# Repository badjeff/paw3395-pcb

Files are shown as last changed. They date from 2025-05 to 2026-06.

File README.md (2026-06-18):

# PAW3395 PCB

PixArt [**PAW3395DM-T6QU**](https://www.pixart.com/products-detail/129/PAW3395DM-T6QU) low power laser mouse sensor breakout board.

- Compatible to **PAW3950DM-T5QU**.
- Be operated with 3.3V voltage level ONLY.
- Outlined as narrow as possible for side mount horizontally and perpendicular on low profile keyboards.
- Developed for [zmk-paw3395-driver](https://github.com/badjeff/zmk-paw3395-driver) and [zmk-paw3950-driver](https://github.com/badjeff/zmk-paw3950-driver)

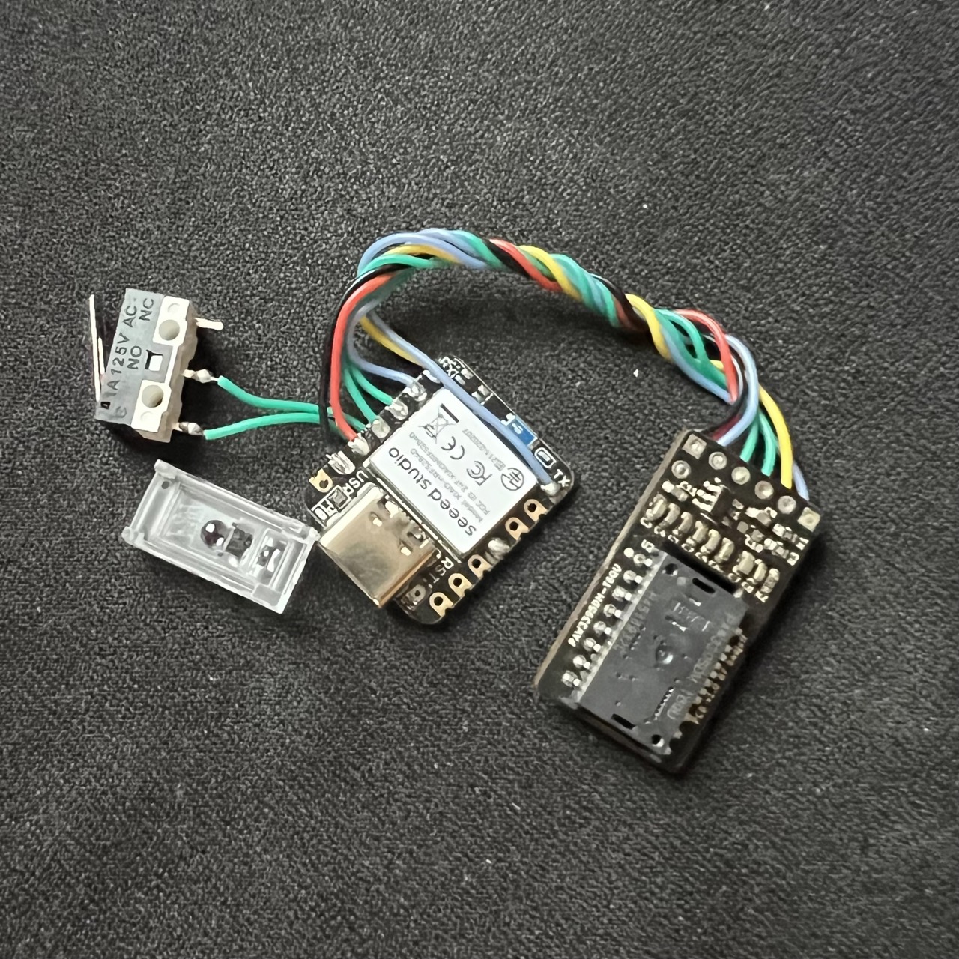
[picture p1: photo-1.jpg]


*Figure 1: Size comparing to Seeed XIAO BLE*

## PCB

Online preview avaliable [here](https://kicanvas.org/?github=https%3A%2F%2Fgithub.com%2Fbadjeff%2Fpaw3395-pcb), powered by [KiCanvas](https://github.com/theacodes/kicanvas).

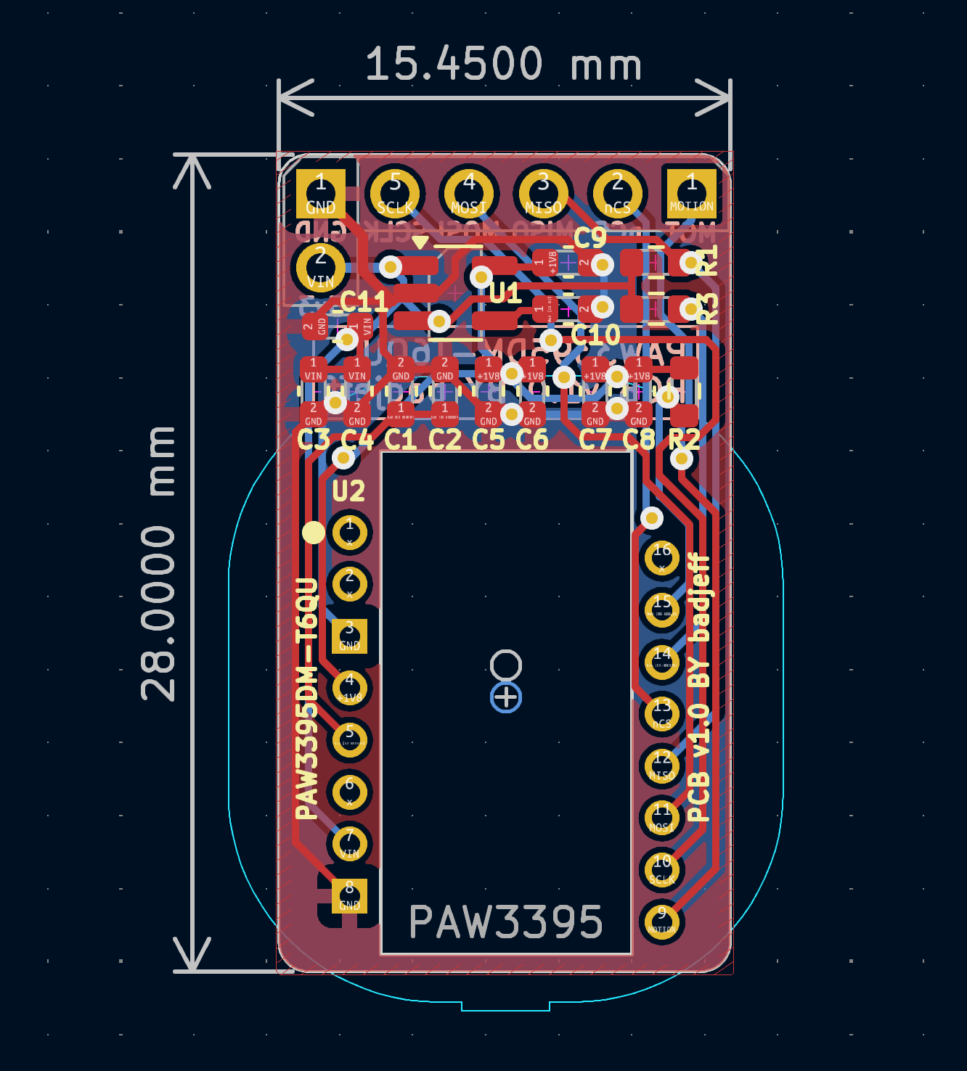
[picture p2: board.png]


*Figure 2: PCB edgecuts dimension*

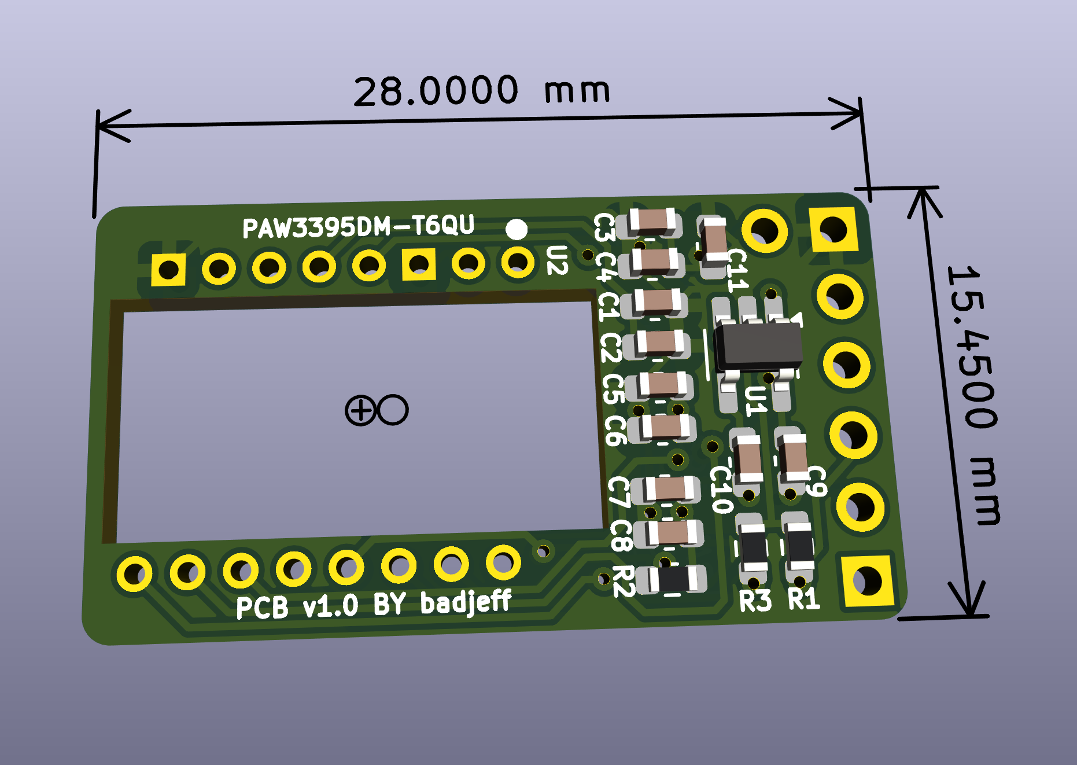
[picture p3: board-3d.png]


*Figure 3: PCB 3D View - 1.6mm FR4*

### BOM

|Designator|Footprint|Quantity|Value|LCSC Part #|
|-|-|-|-|-|
|C1|SMD 0603|1|4.7uF||
|C11, C9|SMD 0603|2|1uF||
|C2, C4, C5|SMD 0603|3|100nF||
|C3, C6, C8|SMD 0603|3|10uF||
|C7|SMD 0603|1|22uF||
|C10|SMD 0603|1|DNI||
|R1|SMD 0603|1|10K|C25804|
|R2|SMD 0603|1|4.7|C23164|
|R3|SMD 0603|1|2M|C22976|
|U1|SOT-23-5|1|TLV74318PDBVR||
|U2|PAW3395DM-T6QU|1|PAW3395||
|  |PAW3950DM-T5QU|1|PAW3950||

- DNI: don't install.
- SMD 0603 (Imperial) aka 1608 Metric.
- ~~`U1` LDO can be replace by RT9193-18GB, change `C10` to 22nF.~~
- `U1` LDO can be replace by XC6219B182MR or TLV75519PDBVR
- `C1` can be replace by 3.3uF.
- For **PAW3395** Option
  * PAW3395DM-T6QU needs to be used with *compact* LOAE-LSI1 lens, or *chonky* LM19-LSI lens.
- For **PAW3950** Option
  * PAW3950DM-T5QU needs to be used with *compact* LOAE-LSI1 lens, or *chonky* LM19-LSI lens.
  * `R1` should be DNI
  * `R2` should be closed (with zero ohm resistor)
  * Pin 2 & 3 should be connecting with a 2.2uf capicator

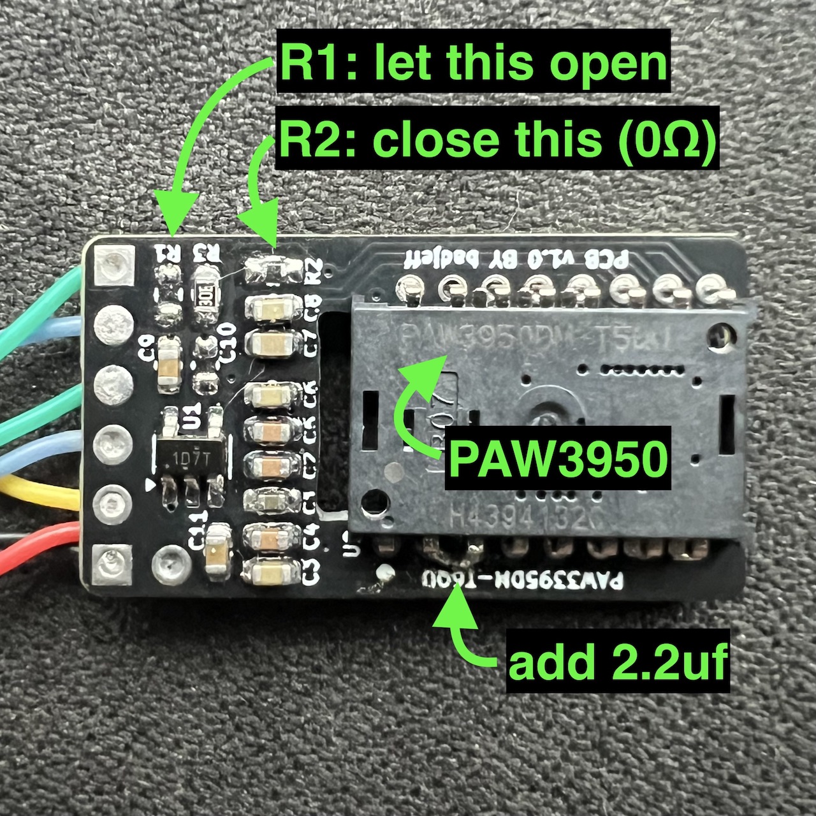
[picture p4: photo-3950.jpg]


*Figure 4: PAW3950 option

### Board Characteristics

- Copper layer count: 2
- Board thickness: 1.6 mm
- Board overall dimensions: 15.5 x 28 mm

### Voltage level config

- 3.3V logic
- VIN: 3.3V

## License

Available under the [CERN-OHL-P v2](/LICENSE) permissive license.

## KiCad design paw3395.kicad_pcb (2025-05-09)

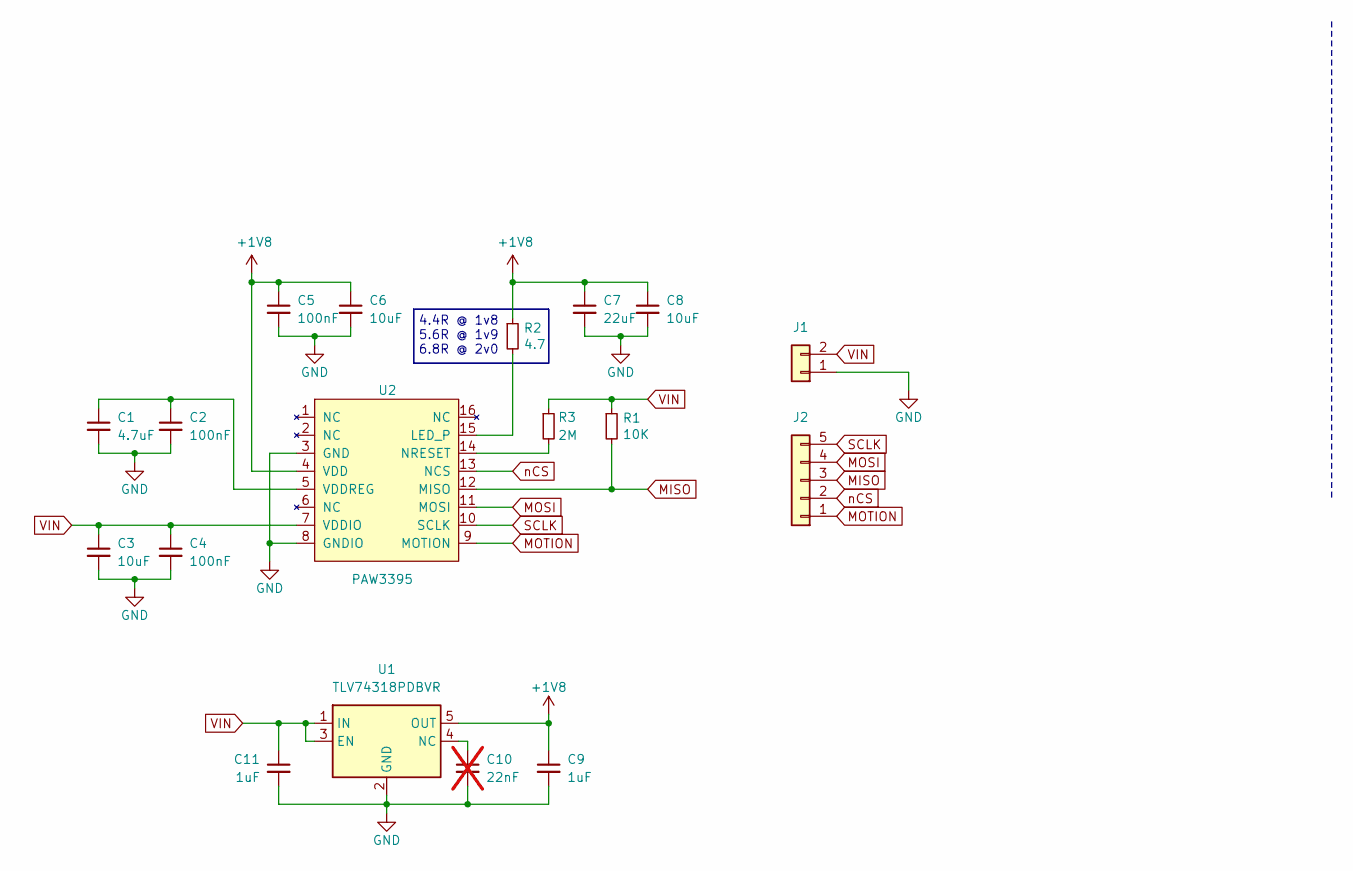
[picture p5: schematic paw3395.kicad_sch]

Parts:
C1: 4.7uF; C_0603_1608Metric
C2, C4, C5: 100nF; C_0603_1608Metric
C3, C6, C8: 10uF; C_0603_1608Metric
C7: 22uF; C_0603_1608Metric
C9, C11: 1uF; C_0603_1608Metric
C10: 22nF; C_0603_1608Metric; not fitted
J1: Conn_01x02; PinHeader_1x02_P2.54mm_Vertical
J2: Conn_01x05; PinHeader_1x05_P2.54mm_Vertical
R1: 10K; R_0603_1608Metric; LCSC C25804
R2: 4.7; R_0603_1608Metric; LCSC C23164
R3: 2M; R_0603_1608Metric; LCSC C22976
U1: TLV74318PDBVR; SOT-23-5_HandSoldering
U2: PAW3395

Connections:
+1V8: C5.1, C6.1, C7.1, C8.1, C9.1, R2.1, U1.5 (OUT), U2.4 (VDD)
GND: C1.2, C2.2, C3.2, C4.2, C5.2, C6.2, C7.2, C8.2, C9.2, C10.2, C11.2, J1.1, U1.2 (GND), U2.3 (GND), U2.8 (GNDIO)
MISO: J2.3, R1.2, U2.12 (MISO)
MOSI: J2.4, U2.11 (MOSI)
MOTION: J2.1, U2.9 (MOTION)
unnamed: C10.1, U1.4 (NC)
unnamed: R2.2, U2.15 (LED_P)
unnamed: R3.2, U2.14 (NRESET)
unnamed: C1.1, C2.1, U2.5 (VDDREG)
SCLK: J2.5, U2.10 (SCLK)
VIN: C3.1, C4.1, C11.1, J1.2, R1.1, R3.1, U1.1 (IN), U1.3 (EN), U2.7 (VDDIO)
nCS: J2.2, U2.13 (NCS)

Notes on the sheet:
4.4R @ 1v8 5.6R @ 1v9 6.8R @ 2v0

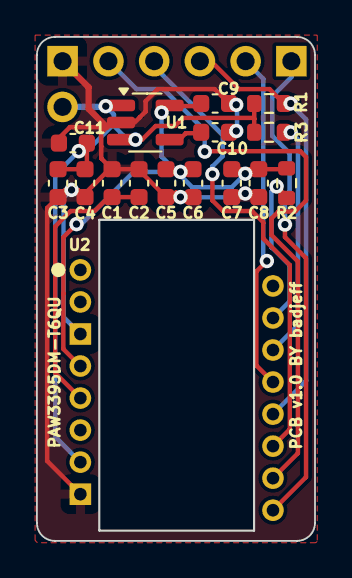
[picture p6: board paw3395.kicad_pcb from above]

Board: 2 copper layers, 15.4 x 28.0 mm, 18 parts (0 on the bottom side), 12 nets.
